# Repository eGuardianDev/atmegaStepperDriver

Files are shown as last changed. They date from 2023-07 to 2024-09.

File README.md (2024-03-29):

# atmegaStepperDriver  
  Open source stepper driver powered by Atmega chip

## Quick Description
This project was design to be used in my [Modul3D](https://github.com/eGuardianDev/Modul3D) project.
Now It has its own project.  
The idea to have simple, cheap, open source stepper driver for stepper motor

## Features and design   
- Powered by Atmega chip (at the moment Atmega328)  
- H-Bridge design  
- Flyback Voltage protection  
- Standart stepper driver communication  
- I2C communcation interface
- Fan controll

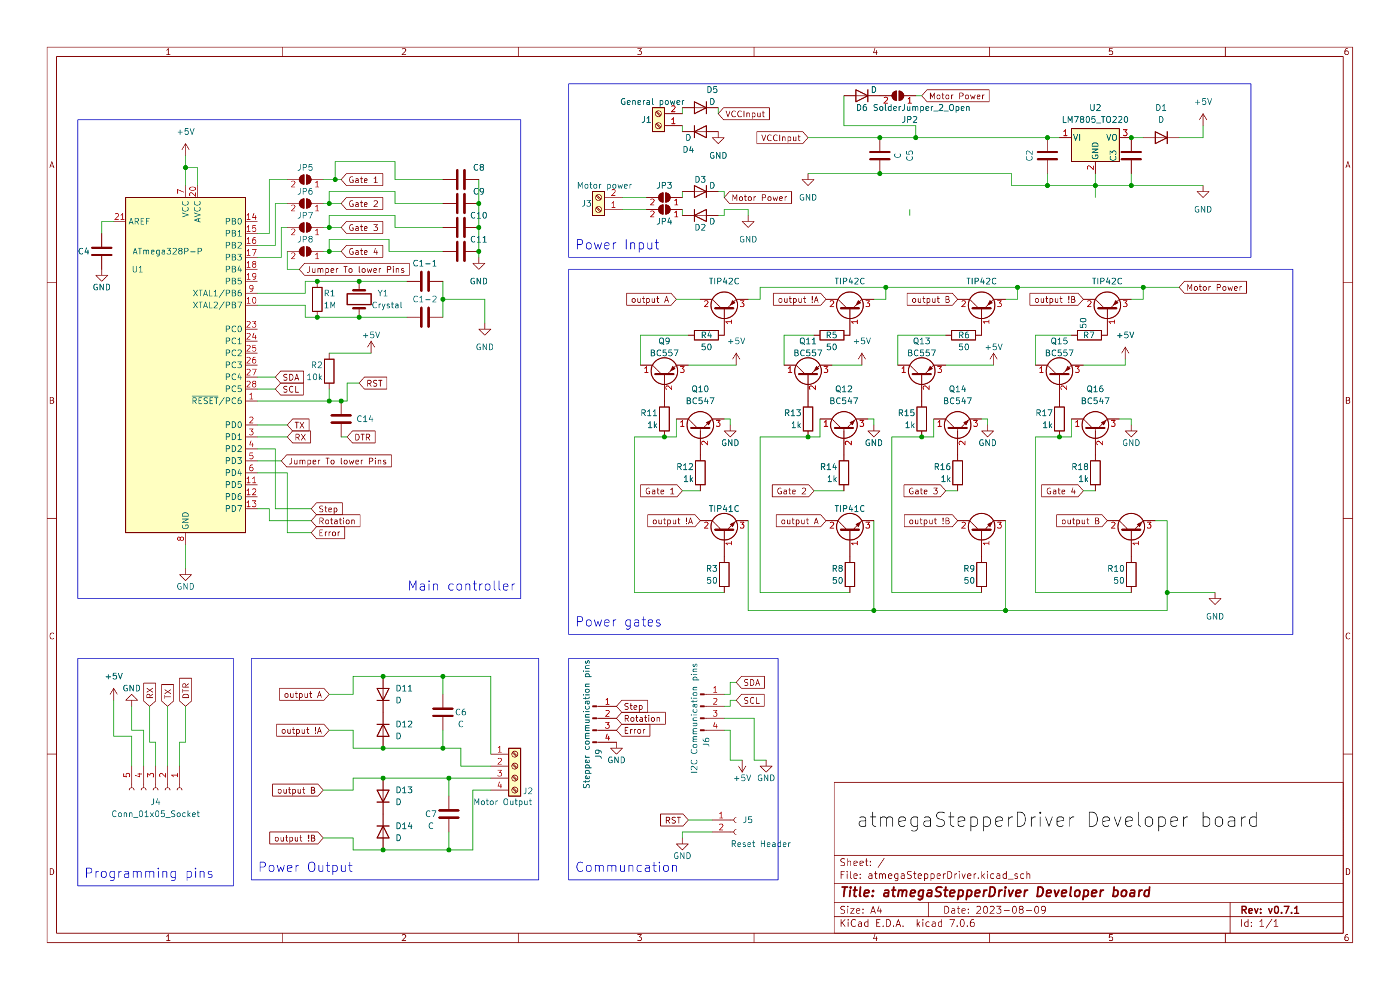
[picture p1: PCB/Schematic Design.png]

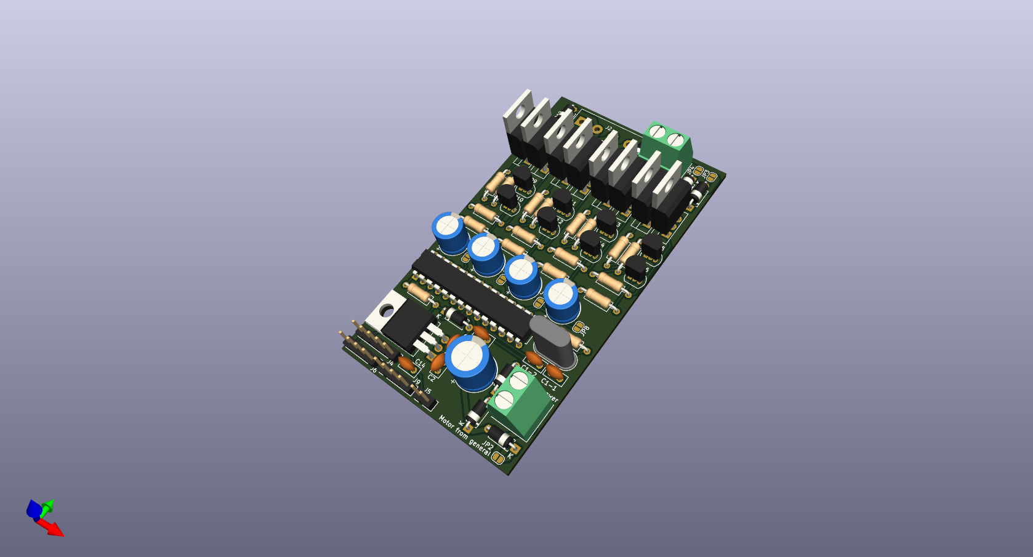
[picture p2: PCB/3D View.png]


## Current Development
### Firmware
 - [ ] Todo...
### Hardware
#### Power
- [X] Power supply for the chip
- [X] Sepreate connection for power for the motor
- [X] Pins for power
#### Main system
- [X] H-bridge configuration
- [X] Connect the pins to the transistor of H-bridge
- [X] Calculate transistor resistor values
#### Communication
- [X] Pins for communication
- [X] I2C pins
- [X] Address Changer
- [ ] Step mode (maybe in next version or firmware based)
#### Protection
- [X] Add capacitor before transitor for smooth curves, but don't test it
- [X] Flyback protection (with ziner diode) 
- [X] Power supply smoothing and return diode
- [ ] Fully test protection system
#### Misc.
- [X] Change diode foot print

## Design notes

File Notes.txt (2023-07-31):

Transitor need specific activation power (amps) to use at full capability
https://forum.arduino.cc/t/custom-h-bridge-circuit-not-working-when-adding-motor/379745
there is problem
if the powered voltage is change that will change the current and the resistors needed to power the grounding transitor
this will be really problematic
the diagram above will make the circuit more compact and use less parts, but can't

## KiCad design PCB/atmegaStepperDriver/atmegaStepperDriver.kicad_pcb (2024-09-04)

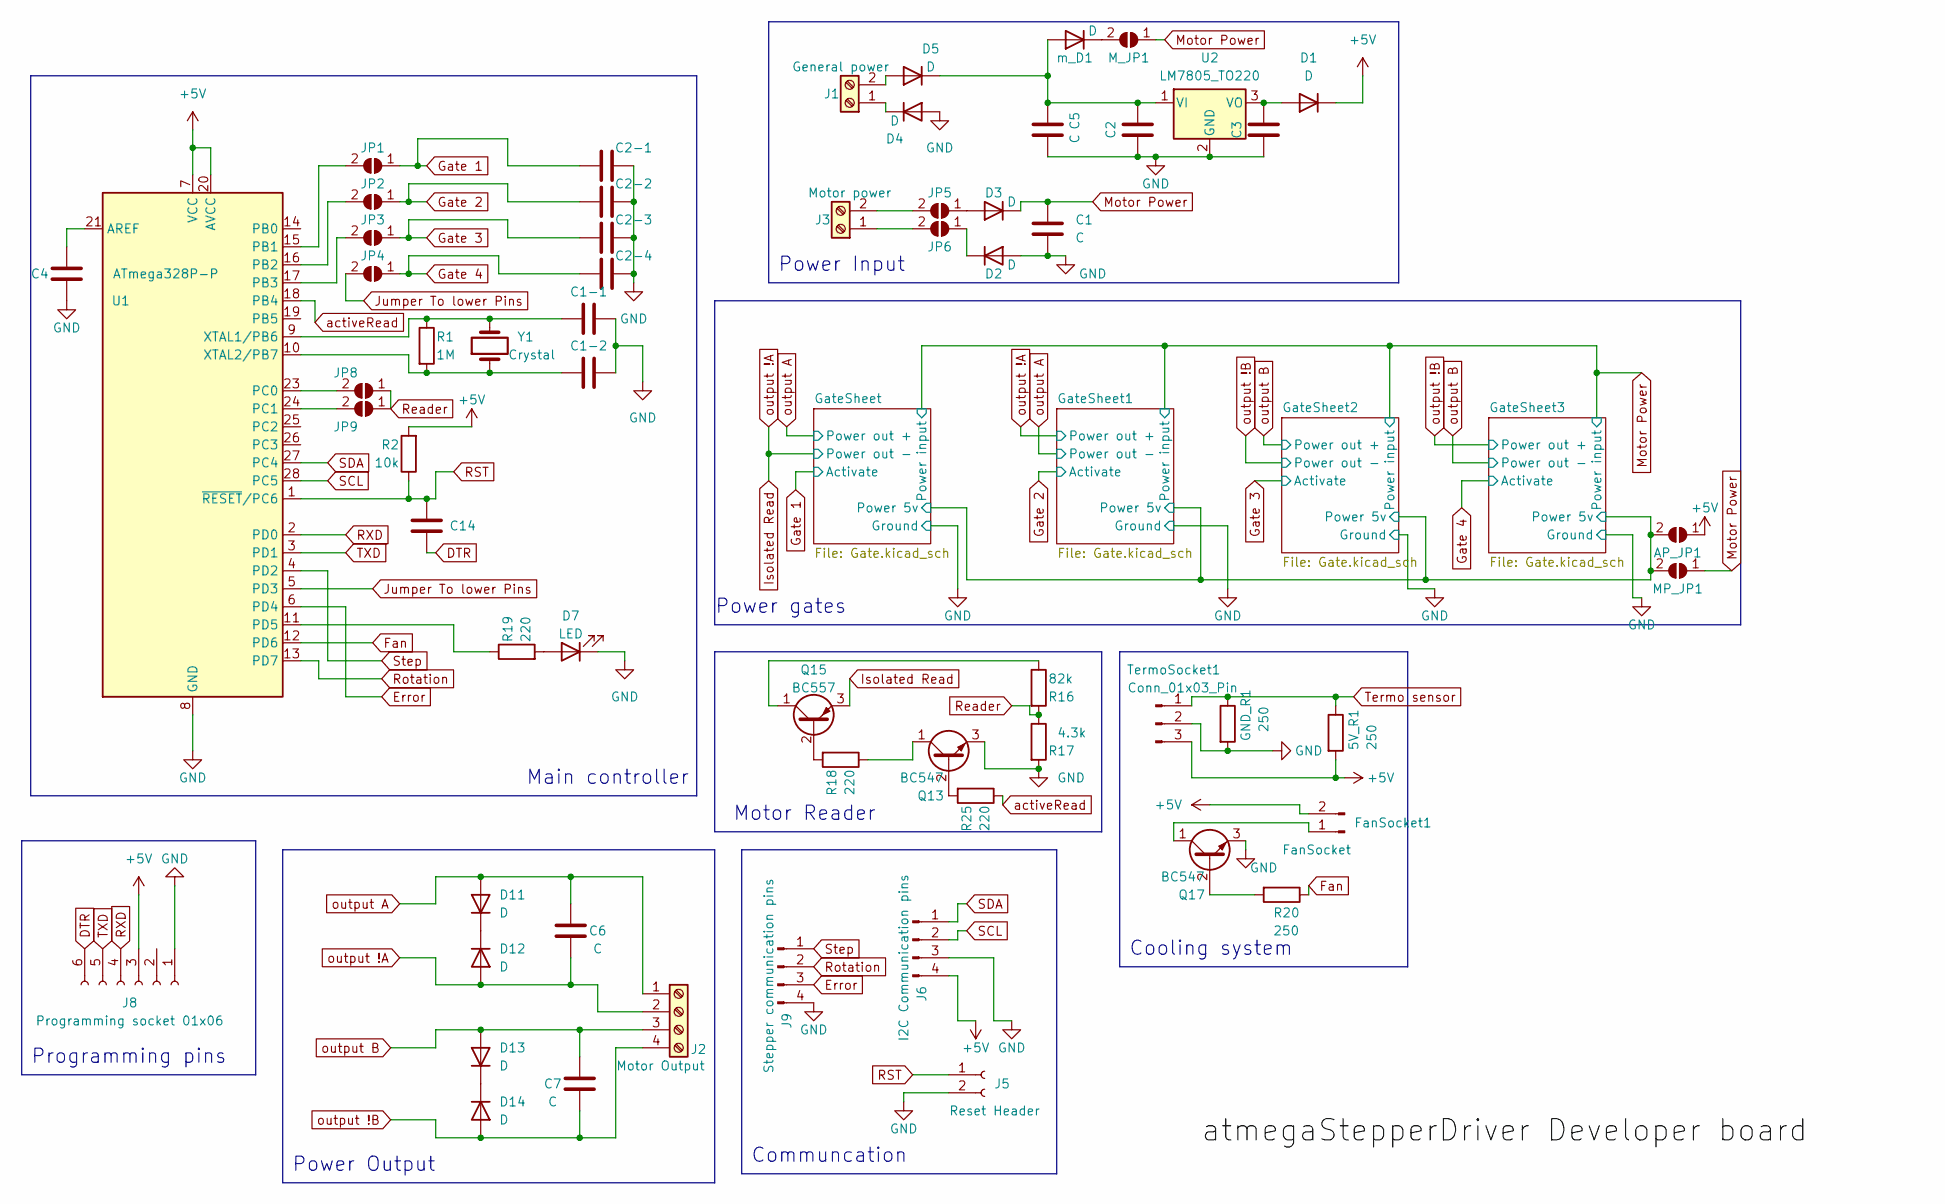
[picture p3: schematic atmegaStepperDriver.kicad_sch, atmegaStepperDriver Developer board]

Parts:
5V_R1: 250; R_Axial_DIN0207_L6.3mm_D2.5mm_P10.16mm_Horizontal
AP_JP1: SolderJumper_2_Open; SolderJumper-2_P1.3mm_Open_RoundedPad1.0x1.5mm
C1, C2-1, C2-2, C2-3, C2-4: C; CP_Radial_D8.0mm_P3.80mm
C1-1, C1-2, C2, C3, C4, C6, C7, C14: C; C_Disc_D5.0mm_W2.5mm_P2.50mm
C5: C; CP_Radial_D10.0mm_P5.00mm
D1, D2, D3, D4, D5, D11, D12, D13, D14: D; D_A-405_P7.62mm_Horizontal
D7: LED; LED_D5.0mm
FanSocket1: FanSocket; PinHeader_1x02_P2.54mm_Vertical
GND_R1: 250; R_Axial_DIN0207_L6.3mm_D2.5mm_P10.16mm_Horizontal
J1: General power; TerminalBlock_Phoenix_MKDS-1,5-2_1x02_P5.00mm_Horizontal
J2: Motor Output; TerminalBlock_bornier-4_P5.08mm
J3: Motor power; TerminalBlock_Phoenix_MKDS-1,5-2_1x02_P5.00mm_Horizontal
J5: Reset Header; PinHeader_1x02_P2.54mm_Vertical
J6: I2C Communication pins; PinHeader_1x04_P2.54mm_Vertical
J8: Programming socket 01x06; PinHeader_1x06_P2.54mm_Vertical
J9: Stepper communication pins; PinHeader_1x04_P2.54mm_Vertical
JP1, JP2, JP3, JP4, JP5, JP6, JP8, JP9: SolderJumper_2_Open; SolderJumper-2_P1.3mm_Open_RoundedPad1.0x1.5mm
MP_JP1: SolderJumper_2_Open; SolderJumper-2_P1.3mm_Open_RoundedPad1.0x1.5mm
M_JP1: SolderJumper_2_Open; SolderJumper-2_P1.3mm_Open_RoundedPad1.0x1.5mm
Q13, Q17: BC547; TO-92_Inline
Q15: BC557; TO-92_Inline
R1: 1M; R_Axial_DIN0207_L6.3mm_D2.5mm_P10.16mm_Horizontal
R2: 10k; R_Axial_DIN0207_L6.3mm_D2.5mm_P10.16mm_Horizontal
R16: 82k; R_Axial_DIN0207_L6.3mm_D2.5mm_P10.16mm_Horizontal
R17: 4.3k; R_Axial_DIN0207_L6.3mm_D2.5mm_P10.16mm_Horizontal
R18, R19, R25: 220; R_Axial_DIN0207_L6.3mm_D2.5mm_P10.16mm_Horizontal
R20: 250; R_Axial_DIN0207_L6.3mm_D2.5mm_P10.16mm_Horizontal
TermoSocket1: Conn_01x03_Pin; PinHeader_1x03_P2.54mm_Vertical
U1: ATmega328P-P; DIP-28_W7.62mm
U2: LM7805_TO220; TO-220-3_Vertical
Y1: Crystal; Crystal_HC49-U_Vertical
m_D1: D; D_A-405_P7.62mm_Horizontal

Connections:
+5V: 5V_R1.2, AP_JP1.1 (A), D1.1 (K), FanSocket1.2, J6.4, J8.3, R2.2, TermoSocket1.3, U1.7 (VCC), U1.20 (AVCC)
/GateSheet/Power 5v: AP_JP1.2 (B), MP_JP1.2 (B); also elsewhere on the board
DTR: C14.1, J8.6
Error: J9.3, U1.6 (PD4)
Fan: R20.1, U1.12 (PD6)
GND: C1.2, C1-1.2, C1-2.2, C2.1, C2-1.2, C2-2.2, C2-3.2, C2-4.2, C3.1, C4.1, C5.2, D2.2 (A), D4.2 (A), D7.1 (K), GND_R1.2, J5.2, J6.3, J8.1, J9.4, Q13.3 (E), Q17.3 (E), R17.2, TermoSocket1.2, U1.8 (GND), U1.22 (GND), U2.2 (GND); also elsewhere on the board
Gate 1: C2-1.1, JP1.1 (A); also elsewhere on the board
Gate 2: C2-2.1, JP2.1 (A); also elsewhere on the board
Gate 3: C2-3.1, JP3.1 (A); also elsewhere on the board
Gate 4: C2-4.1, JP4.1 (A); also elsewhere on the board
Isolated Read: C6.1, D12.2 (A), J2.2, Q15.3 (E); also elsewhere on the board
Jumper To lower Pins: JP4.2 (B), U1.5 (PD3)
Motor Power: C1.1, D3.1 (K), MP_JP1.1 (A), M_JP1.1 (A); also elsewhere on the board
unnamed: C3.2, D1.2 (A), U2.3 (VO)
unnamed: D2.1 (K), JP6.1 (A)
unnamed: D3.2 (A), JP5.1 (A)
unnamed: D4.1 (K), J1.1
unnamed: D5.2 (A), J1.2
unnamed: C2.2, C5.1, D5.1 (K), U2.1 (VI), m_D1.2 (A)
unnamed: D7.2 (A), R19.2
unnamed: D11.1 (K), D12.1 (K)
unnamed: D13.1 (K), D14.1 (K)
unnamed: FanSocket1.1, Q17.1 (C)
unnamed: J3.1, JP6.2 (B)
unnamed: J3.2, JP5.2 (B)
unnamed: JP1.2 (B), U1.15 (PB1)
unnamed: JP2.2 (B), U1.16 (PB2)
unnamed: JP3.2 (B), U1.17 (PB3)
unnamed: JP8.2 (B), U1.23 (PC0)
unnamed: JP9.2 (B), U1.24 (PC1)
unnamed: M_JP1.2 (B), m_D1.1 (K)
unnamed: Q13.2 (B), R25.2
unnamed: Q13.1 (C), R18.1
unnamed: Q15.2 (B), R18.2
unnamed: Q15.1 (C), R16.1
unnamed: Q17.2 (B), R20.2
unnamed: C4.2, U1.21 (AREF)
unnamed: R19.1, U1.11 (PD5)
unnamed: C1-1.1, R1.1, U1.9 (XTAL1/PB6), Y1.2
unnamed: C1-2.1, R1.2, U1.10 (XTAL2/PB7), Y1.1
RST: C14.2, J5.1, R2.1, U1.1 (~RESET/PC6)
RXD: J8.4, U1.2 (PD0)
Reader: JP8.1 (A), JP9.1 (A), R16.2, R17.1
Rotation: J9.2, U1.13 (PD7)
SCL: J6.2, U1.28 (PC5)
SDA: J6.1, U1.27 (PC4)
Step: J9.1, U1.4 (PD2)
TXD: J8.5, U1.3 (PD1)
Termo sensor: 5V_R1.1, GND_R1.1, TermoSocket1.1
activeRead: R25.1, U1.18 (PB4)
output !B: C7.1, D14.2 (A), J2.4; also elsewhere on the board
output A: C6.2, D11.2 (A), J2.1; also elsewhere on the board
output B: C7.2, D13.2 (A), J2.3; also elsewhere on the board

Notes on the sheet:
Main controller
Power Input
Programming pins
Communcation
Motor Reader
Cooling system
Power Output
Power gates

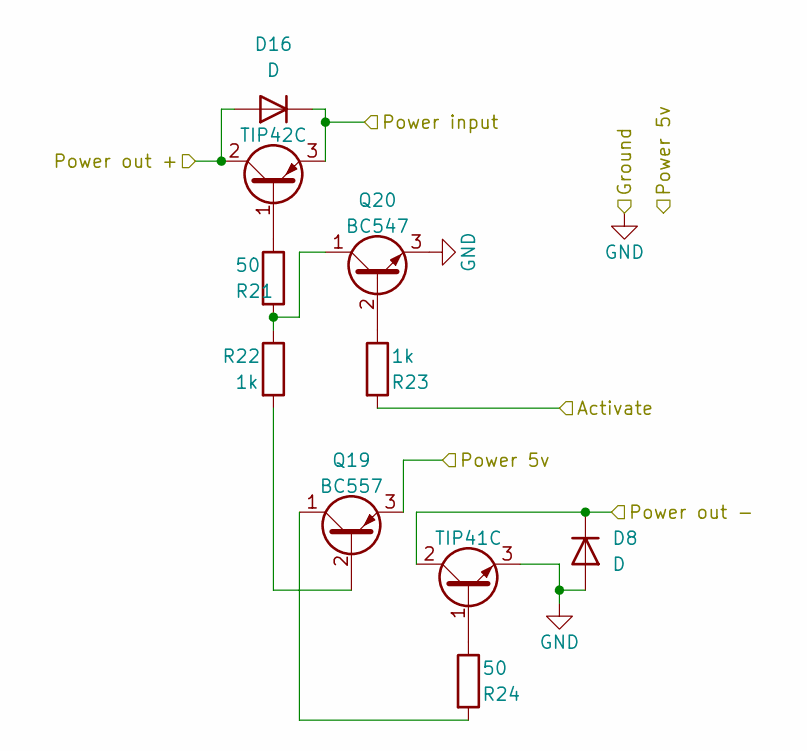
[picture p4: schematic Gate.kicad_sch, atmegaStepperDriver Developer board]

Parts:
D8, D16: D; D_DO-35_SOD27_P10.16mm_Horizontal
Q18: TIP42C; TO-220-3_Vertical
Q19: BC557; TO-92_Inline_Wide
Q20: BC547; TO-92_Inline_Wide
Q21: TIP41C; TO-220-3_Vertical
R21, R24: 50; R_Axial_DIN0207_L6.3mm_D2.5mm_P10.16mm_Horizontal
R22, R23: 1k; R_Axial_DIN0207_L6.3mm_D2.5mm_P10.16mm_Horizontal

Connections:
/GateSheet/Power 5v: Q19.3 (E); also elsewhere on the board
GND: D8.2 (A), Q20.3 (E), Q21.3 (E); also elsewhere on the board
Gate 1: R23.2; also elsewhere on the board
Isolated Read: D8.1 (K), Q21.2 (C); also elsewhere on the board
Motor Power: D16.1 (K), Q18.3 (E); also elsewhere on the board
unnamed: Q18.1 (B), R21.1
unnamed: Q19.2 (B), R22.2
unnamed: Q19.1 (C), R24.2
unnamed: Q20.2 (B), R23.1
unnamed: Q20.1 (C), R21.2, R22.1
unnamed: Q21.1 (B), R24.1
output A: D16.2 (A), Q18.2 (C); also elsewhere on the board

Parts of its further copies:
D9, D10, D15, D17, D18, D19: D; D_DO-35_SOD27_P10.16mm_Horizontal
Q1, Q5, Q9: TIP42C; TO-220-3_Vertical
Q2, Q6, Q10: BC557; TO-92_Inline_Wide
Q3, Q7, Q11: BC547; TO-92_Inline_Wide
Q4, Q8, Q12: TIP41C; TO-220-3_Vertical
R3, R6, R7, R10, R11, R14: 50; R_Axial_DIN0207_L6.3mm_D2.5mm_P10.16mm_Horizontal
R4, R5, R8, R9, R12, R13: 1k; R_Axial_DIN0207_L6.3mm_D2.5mm_P10.16mm_Horizontal

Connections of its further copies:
/GateSheet/Power 5v: Q2.3 (E), Q6.3 (E), Q10.3 (E); also elsewhere on the board
GND: D9.2 (A), D10.2 (A), D15.2 (A), Q3.3 (E), Q4.3 (E), Q7.3 (E), Q8.3 (E), Q11.3 (E), Q12.3 (E); also elsewhere on the board
Gate 2: R5.2; also elsewhere on the board
Gate 3: R9.2; also elsewhere on the board
Gate 4: R13.2; also elsewhere on the board
Isolated Read: D17.2 (A), Q1.2 (C); also elsewhere on the board
Motor Power: D17.1 (K), D18.1 (K), D19.1 (K), Q1.3 (E), Q5.3 (E), Q9.3 (E); also elsewhere on the board
unnamed: Q1.1 (B), R3.1
unnamed: Q2.2 (B), R4.2
unnamed: Q2.1 (C), R6.2
unnamed: Q3.2 (B), R5.1
unnamed: Q3.1 (C), R3.2, R4.1
unnamed: Q4.1 (B), R6.1
unnamed: Q5.1 (B), R7.1
unnamed: Q6.2 (B), R8.2
unnamed: Q6.1 (C), R10.2
unnamed: Q7.2 (B), R9.1
unnamed: Q7.1 (C), R7.2, R8.1
unnamed: Q8.1 (B), R10.1
unnamed: Q9.1 (B), R11.1
unnamed: Q10.2 (B), R12.2
unnamed: Q10.1 (C), R14.2
unnamed: Q11.2 (B), R13.1
unnamed: Q11.1 (C), R11.2, R12.1
unnamed: Q12.1 (B), R14.1
output !B: D10.1 (K), D19.2 (A), Q8.2 (C), Q9.2 (C); also elsewhere on the board
output A: D9.1 (K), Q4.2 (C); also elsewhere on the board
output B: D15.1 (K), D18.2 (A), Q5.2 (C), Q12.2 (C); also elsewhere on the board

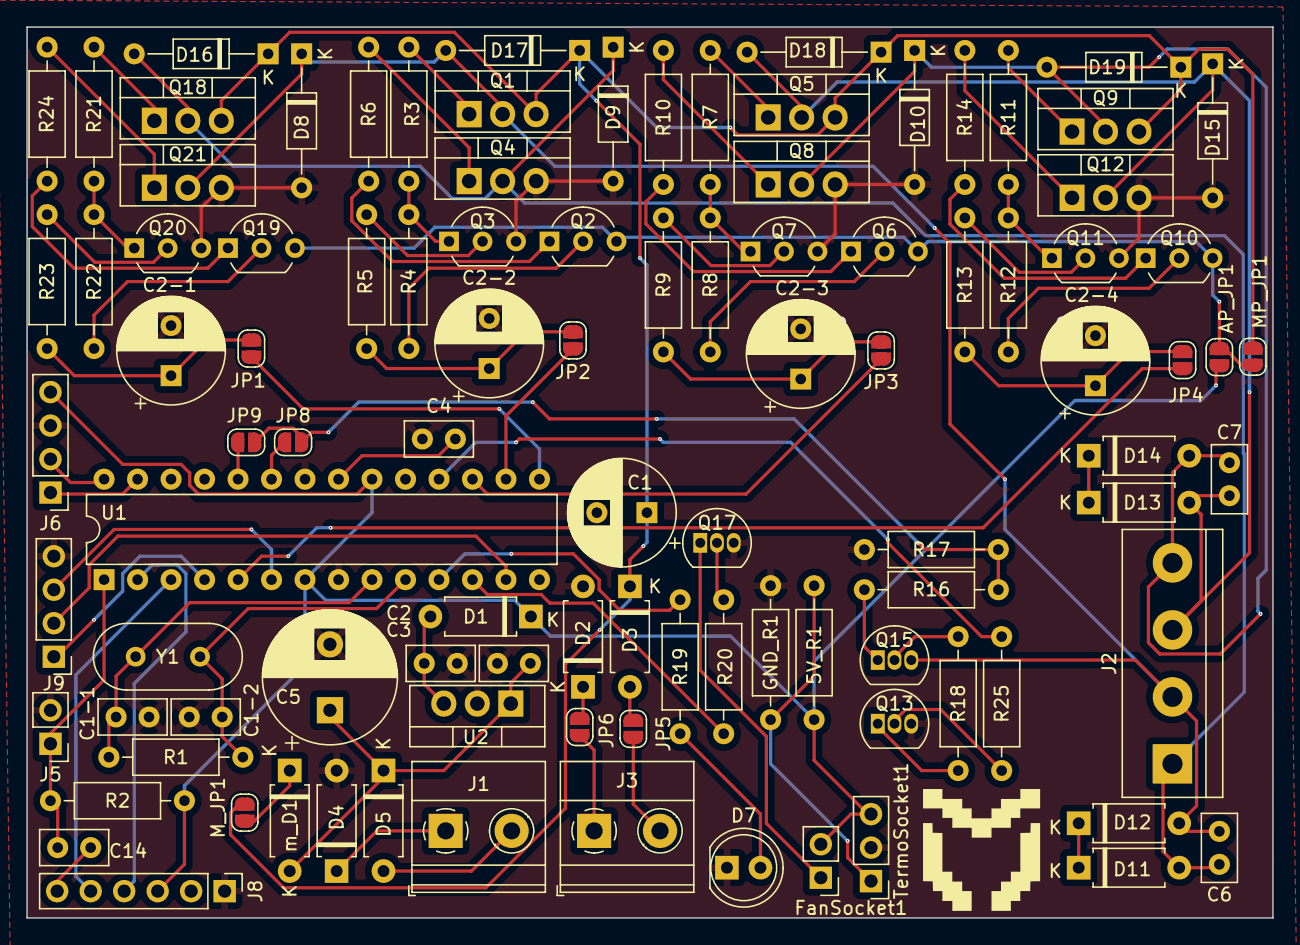
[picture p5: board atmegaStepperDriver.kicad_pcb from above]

Board: 2 copper layers, 94.5 x 67.6 mm, 101 parts (0 on the bottom side), 77 nets.

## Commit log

2023-07-29 pcb design; unfinished;
    [atmegaStepperDriver.kicad_pcb, atmegaStepperDriver.kicad_sch]
2023-07-31 added seprate power supply box; tested protection circuit; added inputs for power;
    [atmegaStepperDriver.kicad_sch]
2023-07-31 added programmable pins; fixed footprints; removed old protection; separated few sectors
    [atmegaStepperDriver.kicad_sch]
2023-08-03 pcb desing started; lower level transistors added; fast pwm tested
    [atmegaStepperDriver.kicad_pcb, atmegaStepperDriver.kicad_sch]
2023-08-06 communication pins;
    [atmegaStepperDriver.kicad_pcb, atmegaStepperDriver.kicad_sch]
2023-08-07 General design ready; footprints ready; V0.0.5
    [atmegaStepperDriver.kicad_pcb, atmegaStepperDriver.kicad_sch]
2023-08-07 change capacitor footprint; added few pictures;
    [atmegaStepperDriver.kicad_sch]
2023-08-07 All general connections ready; further check needed; V0.0.6
    [atmegaStepperDriver.kicad_pcb, atmegaStepperDriver.kicad_sch]
2023-08-09 Footprint done; ready for testing; drc clear; Gerber files;V0.7.1;
    [atmegaStepperDriver-B_Cu.gbr, atmegaStepperDriver-B_Mask.gbr, atmegaStepperDriver-B_Paste.gbr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]
2023-08-10 Updated pictures to new version
    [atmegaStepperDriver-B_Cu.gbr, atmegaStepperDriver-B_Mask.gbr, atmegaStepperDriver-B_Paste.gbr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]
2023-08-25 new design; the old one doesn't work; to be finished;
    [atmegaStepperDriver.kicad_sch]
2023-08-29 fixed old design flaw; full redisgn; Few things to be done; V0.8.0;
    [atmegaStepperDriver.kicad_pcb, atmegaStepperDriver.kicad_sch]
2023-08-29 traces fixed; fan added; V0.8.1
    [atmegaStepperDriver.kicad_pcb, atmegaStepperDriver.kicad_sch]
2023-08-30 added transistor for fan; final checks; Gerber files ready; V0.8.2
    [atmegaStepperDriver-B_Cu.gbr, atmegaStepperDriver-B_Mask.gbr, atmegaStepperDriver-B_Paste.gbr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]
2023-08-30 changed version on board back
    [atmegaStepperDriver-B_Cu.gbr, atmegaStepperDriver-B_Mask.gbr, atmegaStepperDriver-B_Paste.gbr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]
2023-09-15 fixed bad transistors; readme; V0.8.3
    [atmegaStepperDriver.kicad_pcb, atmegaStepperDriver.kicad_sch]
2024-03-29 posible fix, need more research + for the streak
    [Gate.kicad_sch, atmegaStepperDriver.kicad_sch]
2024-04-01 Fix gate; added termistor; gate sheet added; v0.8.4
    [Gate.kicad_sch, atmegaStepperDriver.kicad_pcb, atmegaStepperDriver.kicad_sch]
2024-04-03 Reader for motor movement added; possible resistor on termistor
    [atmegaStepperDriver.kicad_sch]
2024-04-04 Added analog read for motor error
    [atmegaStepperDriver.kicad_pcb, atmegaStepperDriver.kicad_sch]
2024-09-04 someData; idk what i did, forgot to push it
    [Gate.kicad_sch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]
